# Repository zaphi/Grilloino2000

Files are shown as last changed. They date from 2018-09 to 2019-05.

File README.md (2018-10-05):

# Grilloino2000

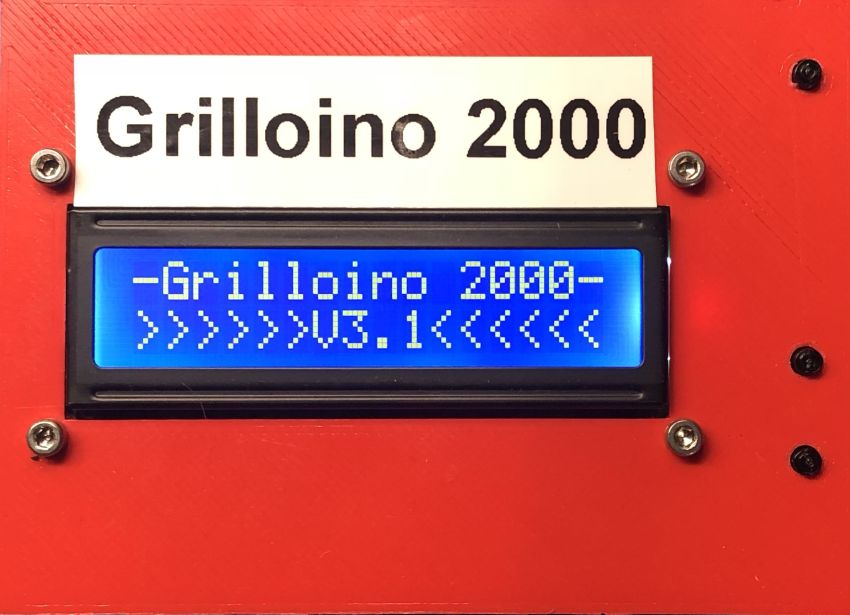
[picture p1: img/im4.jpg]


ESP8266 Grillthermometer

Als leidenschaftlicher Griller war es dies Jahr zeit für einen Smoker! Da kaufen nicht in frage kommt wurde der Bau eines UDS geplant. Und da ich in der Nacht gerne Schlafe und nicht alle halbe Stunde zum Smoker laufen möchte, musste man hier automatisieren.

Bauteile:
- ESP8266 NodeMCU
- 4051N Analogmultiplexer
- 16x2 LCD
- kleinkram... siehe BOM.txt

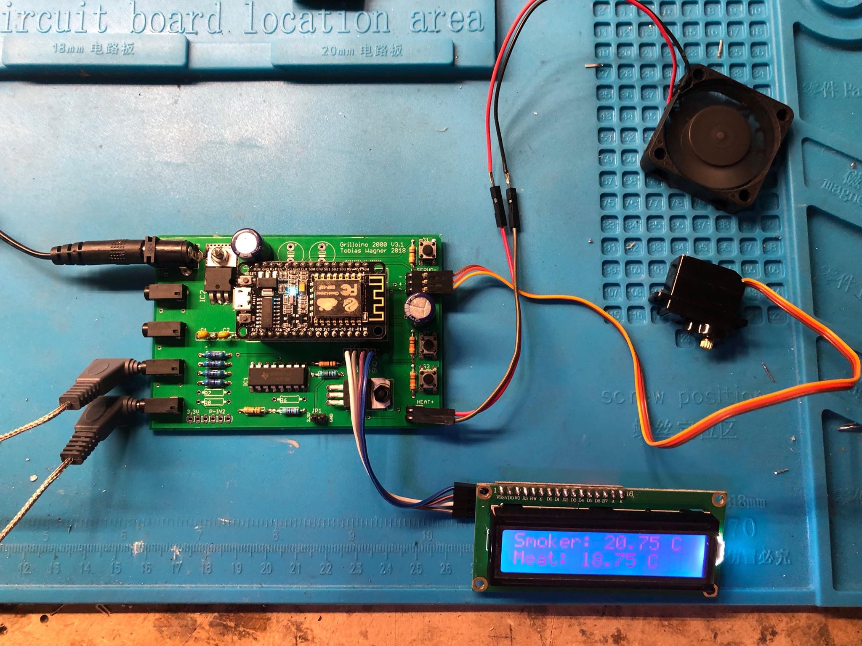
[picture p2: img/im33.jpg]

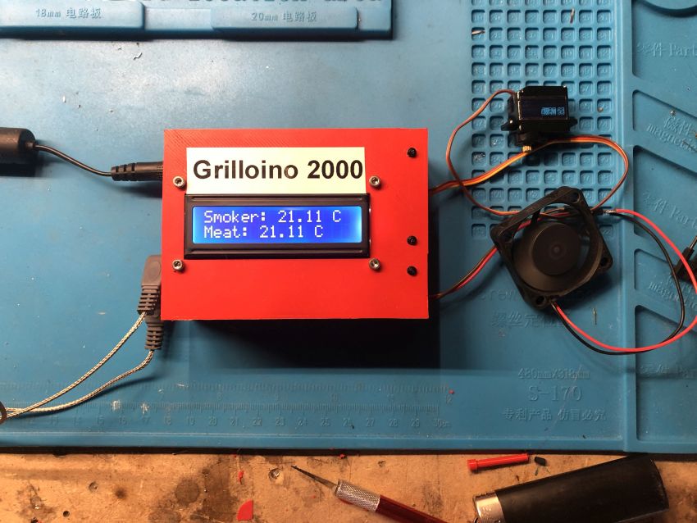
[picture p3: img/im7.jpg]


Funktionen:
- 1x Garraum
- 1-3x Kerntemperatur
- WIFI
- Handy App mittels Blynk
- Thingspeak Logging
- Pitmaster (Lüfter/Klappe)
- Push Nachrichten
- HTTP Server (wird vermutlich entfernt)

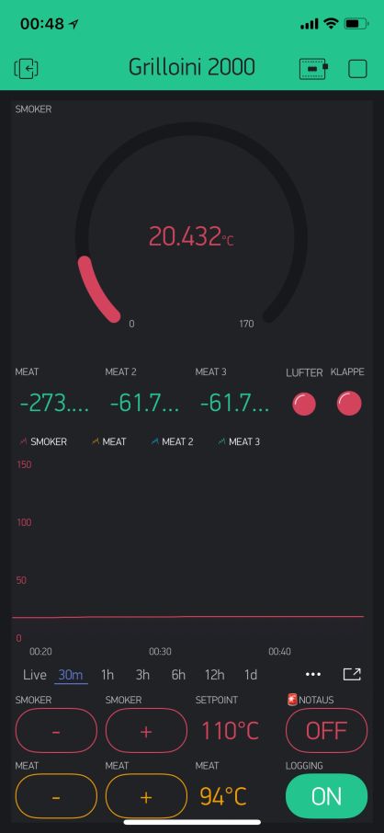
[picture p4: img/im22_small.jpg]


Aktueller Projektstand:
- PCB V3.1 incl. Buttons 
- 3D Druck Gehäuse

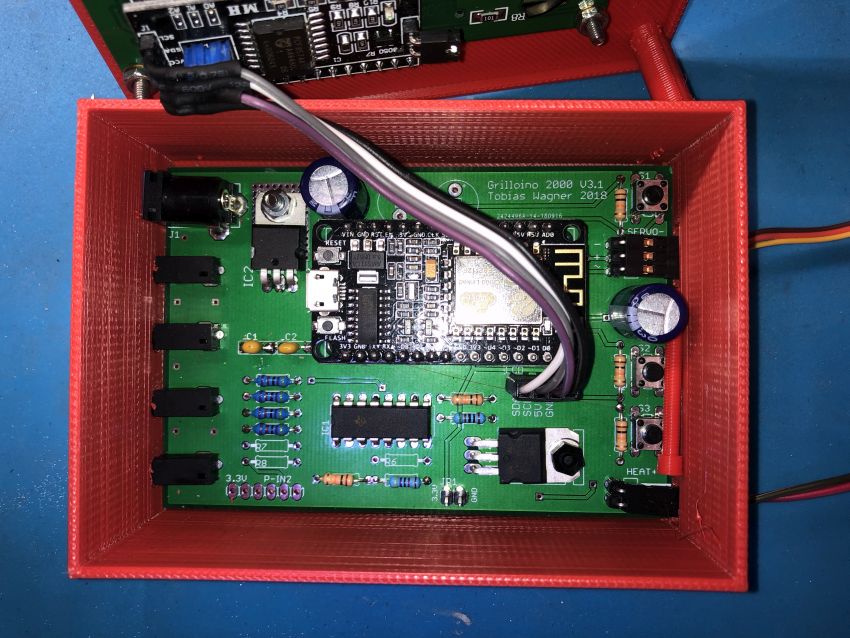
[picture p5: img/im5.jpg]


ToDo:
- korrektur Polung DC Stecker in PCB V3.2

HowTo:
- Es können theoretisch  alle Fühler verwendet werden die auch beim [WLANThermo V2](https://github.com/WLANThermo/WLANThermo_v2/tree/master/software/usr/share/doc/WLANThermo/probedata) funktionieren. Dort wird auch mittels der Steinhart-Hart-Gleichung gerechnet somit können die Parameter A,B,C und Rn übernommen werden. Danke für das vermessen der  Sensoren :-)

Aktuell eingepflegt:
- Maverick ET-7/71/72/73/77/901b
- Maverick ET-735
- Maverick ET-732/733
- Ikkea Fantast
- Ikkea Fantast Neu

Einstellungen für Blynk:
- char auth[] = "PUT YOUR CODE HEAR";

Einstellungen Thingspeak
- const int channelID = Your ID;
- String writeAPIKey = "Your Key";

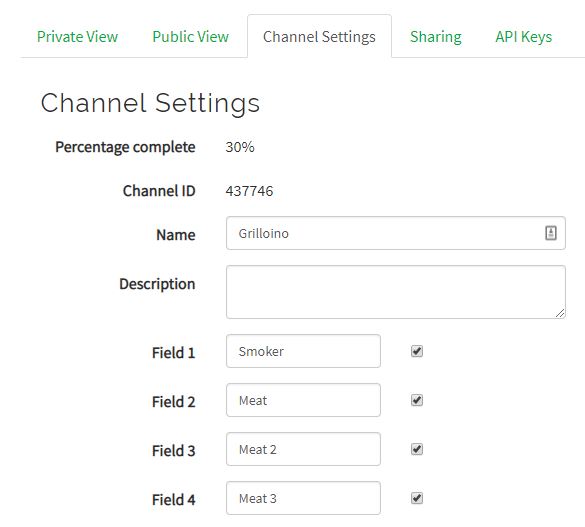
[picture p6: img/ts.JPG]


Messen und Korrektur V3.3:
- Spannung an JP1 messen und im Code eintragen z.B. 3.293V
- float vin = 3.293;  

Button S1:
- Startet WiFi Konfigurations Mode. Grilloino wird als AP im Handy sichtbar und kann mit jedem beliebigen
Hotspot verubnden werden.

Button S2:
- Doppelklick -> Menü Seite -
- Einfach Klick -> Wert +1
- Langer Klick -> Wert ++

Button S3:
- Doppelklick -> Menü Seite +
- Einfach Klick -> Wert -1
- Langer Klick -> Wert --
- Langer Klick nicht im Menü -> anzeige Spannung, IP und RSSI

Bauteile:
- R1-R4 47kOhm Messwiderstand
- R5 560 Ohm
- R9,R10,R11,R13,R14 10kOhm
- R12 47 kOhm

- C1 0,33uf
- C2 0,1uf
- C3,C4,C5,C6 1000 uf
- IC2 LM7805
- Q1 STP36NF06L
- IC1 4051N

Benötigte libraries:

- [Wifi Manager](https://github.com/tzapu/WiFiManager)
- [OneButton](https://github.com/mathertel/OneButton)
- [Timer](https://github.com/JChristensen/Timer)
- [LiquidCrystal-I2C-library](https://github.com/fdebrabander/Arduino-LiquidCrystal-I2C-library)
- [Blynk](https://github.com/blynkkk/blynk-library/releases/tag/v0.5.4)
- [PID-Library](https://github.com/br3ttb/Arduino-PID-Library)

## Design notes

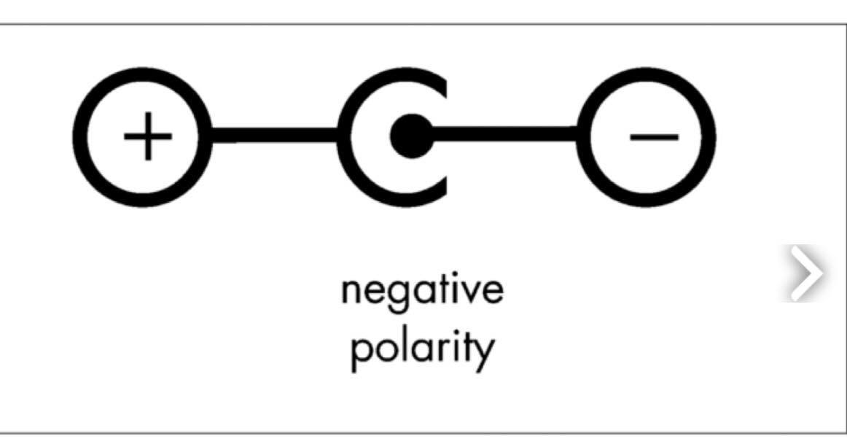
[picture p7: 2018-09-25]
img/pinoout.jpg

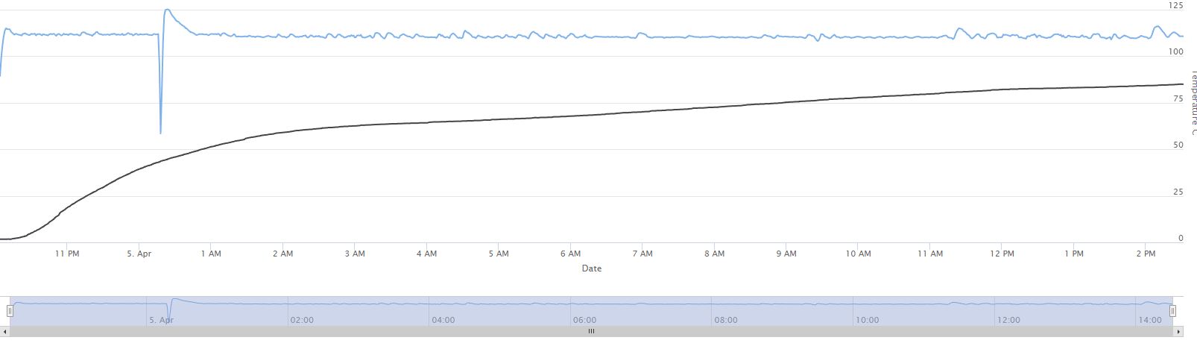
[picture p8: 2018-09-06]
img/te.JPG

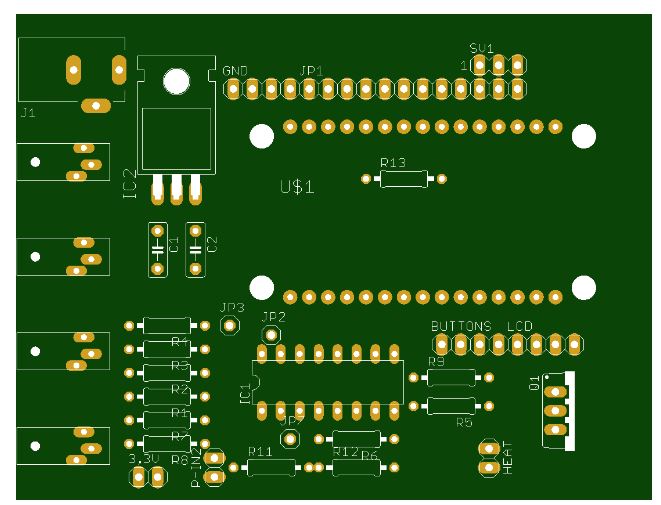
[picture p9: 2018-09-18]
img/pcb_v3.JPG

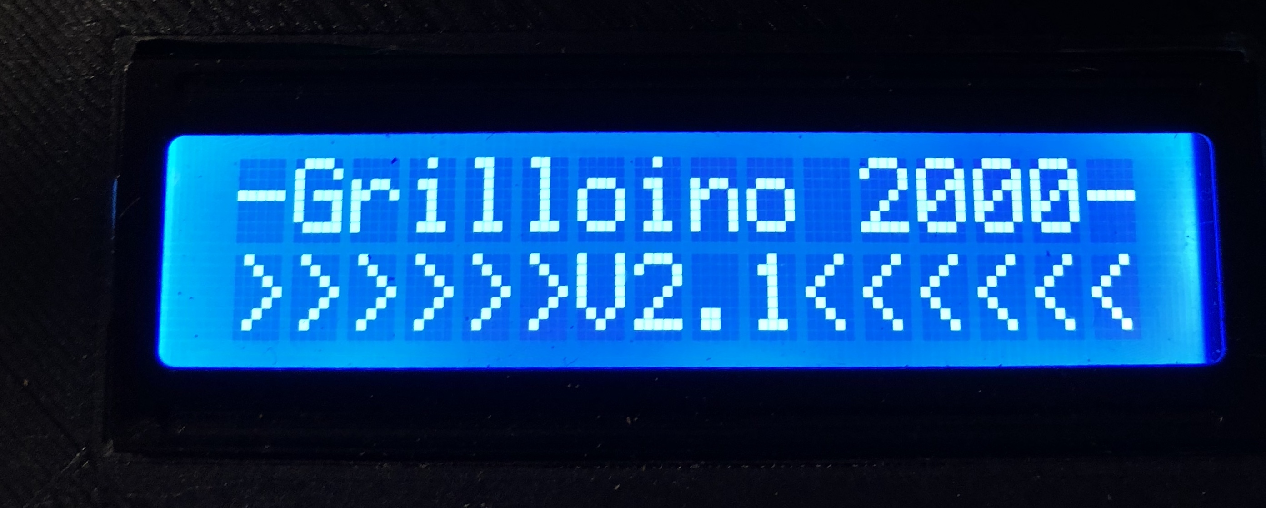
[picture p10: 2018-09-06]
img/im1.jpg

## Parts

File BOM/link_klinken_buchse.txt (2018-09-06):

https://www.digitalo.de/products/366744/Klinken-Steckverbinder-2.5mm-Buchse-Einbau-horizontal-Polzahl-2-Mono-Schwarz-1St..html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

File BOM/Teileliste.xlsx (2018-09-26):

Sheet: Teileliste
Bezeichnung | Wert | Stückzahl | Preis | Preis Gesamt | Link
Messwiderstand 0,1% | 47K | 4 | 0.35 € | 1.40 € | https://www.reichelt.de/widerstand-metallschicht-47-kohm-0207-0-6-w-0-1-mpr-47-0k-p12982.html?trstct=pol_6
Widerstand | 47k | 1 | 0.10 € | 0.10 € | https://www.reichelt.de/5-Kohleschichtwiderstaende/2/index.html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
Widerstand | 10k | 5 | 0.10 € | 0.52 € | https://www.reichelt.de/widerstand-kohleschicht-10-kohm-0207-250-mw-5-1-4w-10k-p1338.html?trstct=pos_2
Widerstand | 560 Ohm | 1 | 0.10 € | 0.10 € | https://www.reichelt.de/widerstand-kohleschicht-560-ohm-0207-250-mw-5-1-4w-560-p1446.html?trstct=pos_4
N-FET | STP36NF06L | 1 | 0.69 € | 0.69 € | https://www.reichelt.de/mosfet-n-ch-60v-30a-70w-to-220ab-stp-36nf06l-stm-p217327.html?&trstct=pos_0
ESP8266 NodeMCU | ESP8266 | 1 | 7.55 € | 7.55 € | https://www.amazon.de/gp/product/B018E741G4/ref=oh_aui_search_detailpage?ie=UTF8&psc=1
Kondensator | 0,33uF | 1 | 0.22 € | 0.22 € | https://www.reichelt.de/folienkondensator-330nf-50v-rm5-mks2-50-330n-p172678.html?&trstct=pos_1
Kondensator | 0,1uF | 1 | 0.20 € | 0.20 € | https://www.reichelt.de/folienkondensator-100nf-63v-rm5-mks2-63-100n-p12349.html?&trstct=pol_2
Kondensator | 1000uf | 4 | 0.25 € | 1.00 € | https://www.reichelt.de/elko-radial-1-0-mf-6-3-v-rm-3-5-1000h-105-c-20-nhg-a-1-0m-6-3-p200391.html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
Multiplexer | 4051N | 1 | 0.40 € | 0.40 € | https://www.reichelt.de/ic-schaltung-74hct-4051-p3393.html?&trstct=pos_0
Spannungsregler | 7805T | 1 | 0.52 € | 0.52 € | https://www.reichelt.de/spannungsregler-5-v-to-220fp-l7805cp-stm-p216931.html?&trstct=pos_1
Stiftleisten | 2,54 mm Raster | 2 | 0.17 € | 0.34 € | https://www.reichelt.de/36pol-stiftleiste-gerade-rm-2-54-sl-1x36g-2-54-p19504.html?&trstct=pol_0
DC Buchse | DCJ0303 | 1 | 0.99 € | 0.99 € | https://www.reichelt.de/einbaubuchse-aussen-6-3-mm-innen-2-1-mm-dc-bu-072759-p208065.html?trstct=pos_7
Klinkenbuchse | 2,5mm Mono | 4 | 1.13 € | 4.52 € | https://www.conrad.de/de/klinken-steckverbinder-25-mm-buchse-einbau-horizontal-polzahl-2-mono-schwarz-conrad-components-1-st-718780.html
LCD | 16x2 | 1 | 9.80 € | 9.80 € | https://www.reichelt.de/entwicklerboards-display-16-x-2-zeichen-blau-debo-lcd-16x2-bl-p192143.html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
Button | Printtaster | 3 | 0.25 € | 0.75 € | https://www.reichelt.de/printtaster-tht-2-45-n-6-x-6-x-9-5-mm-rnd-210-00196-p226417.html?trstct=pos_3
Verpolungsschutz | Diode 1N4001 | 2 | 0.02 € | 0.04 € | https://www.reichelt.de/gleichrichterdiode-50-v-1-a-do-41-1n-4001-p1723.html?&trstct=pos_0
 |  |  | Gesamt | 29.14 €
Lüfter
Radial Lüfter AVC BA10033B12HP077-F22 95x97x33mm |  | 1 | 4.85 | 4.85 | https://www.ebay.de/itm/Radial-Lufter-AVC-BA10033B12HP077-F22-95x97x33mm-Lufter-Fan-12-V-3600-U-min/183452984131
Mini Servo |  | 1 | 3.99 | 3.99 | https://www.ebay.de/itm/1-2-4-10pcs-9G-SG90-Mini-Gear-Micro-Servo-Motor-Robot-Helicopter-Fernbedienung/123106210417

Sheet: Tabelle1
Part | Value | Device | Package | Library | Sheet
3,3V |  | PINHD-1X2 | 1X02 | pinhead | 1
BUTTONS |  | PINHD-1X4 | 1X04 | pinhead | 1
C1 | 0,33uF | C5/2.5 | C5B2.5 | capacitor-wima | 1
C2 | 0,1uF | C5/2.5 | C5B2.5 | capacitor-wima | 1
GND |  | PINHD-1X4 | 1X04 | pinhead | 1
HEAT |  | PINHD-1X2 | 1X02 | pinhead | 1
IC1 | 4051N | 4051N | DIL16 | 40xx | 1
IC2 | 7805T | 7805T | TO220H | linear | 1
J1 |  | DCJ0303 | DCJ0303 | con-jack | 1
JP1 |  | PINHD-1X12 | 1X12 | pinhead | 1
JP2 |  | PINHD-1X1 | 1X01 | pinhead | 1
JP3 |  | PINHD-1X1 | 1X01 | pinhead | 1
JP7 |  | PINHD-1X1 | 1X01 | pinhead | 1
LCD |  | PINHD-1X4 | 1X04 | pinhead | 1
P-IN2 |  | PINHD-1X2 | 1X02 | pinhead | 1
Q1 | STP36NF06L | IRF540 | TO220BV | transistor-power | 1
R1 | 47k | R-EU_0207/10 | 0207/10 | rcl | 1
R2 | 47k | R-EU_0207/10 | 0207/10 | rcl | 1
R3 | 47k | R-EU_0207/10 | 0207/10 | rcl | 1
R4 | 47k | R-EU_0207/10 | 0207/10 | rcl | 1
R5 | 560 | R-EU_0207/10 | 0207/10 | rcl | 1
R6 | 47k | R-EU_0207/10 | 0207/10 | rcl | 1
R7 | 47k | R-EU_0207/10 | 0207/10 | rcl | 1
R8 | 47k | R-EU_0207/10 | 0207/10 | rcl | 1
R9 | 10k | R-EU_0207/10 | 0207/10 | rcl | 1
R11 | 1k | R-EU_0207/10 | 0207/10 | rcl | 1
R12 | 4k7 | R-EU_0207/10 | 0207/10 | rcl | 1
R13 | 4700 | R-EU_0207/10 | 0207/10 | rcl | 1
SV1 |  | MA03-1 | MA03-1 | con-lstb | 1
U$1 | ESP12E_DEVKIT | ESP12E_DEVKIT | ESP12E_DEVKIT | ESP12E_DEVKIT | 1
U$3 | JACK_2_5 | JACK_2_5 | JACK_2_5 | 2_5mm_jack | 1
U$4 | JACK_2_5 | JACK_2_5 | JACK_2_5 | 2_5mm_jack | 1
U$5 | JACK_2_5 | JACK_2_5 | JACK_2_5 | 2_5mm_jack | 1
U$6 | JACK_2_5 | JACK_2_5 | JACK_2_5 | 2_5mm_jack | 1

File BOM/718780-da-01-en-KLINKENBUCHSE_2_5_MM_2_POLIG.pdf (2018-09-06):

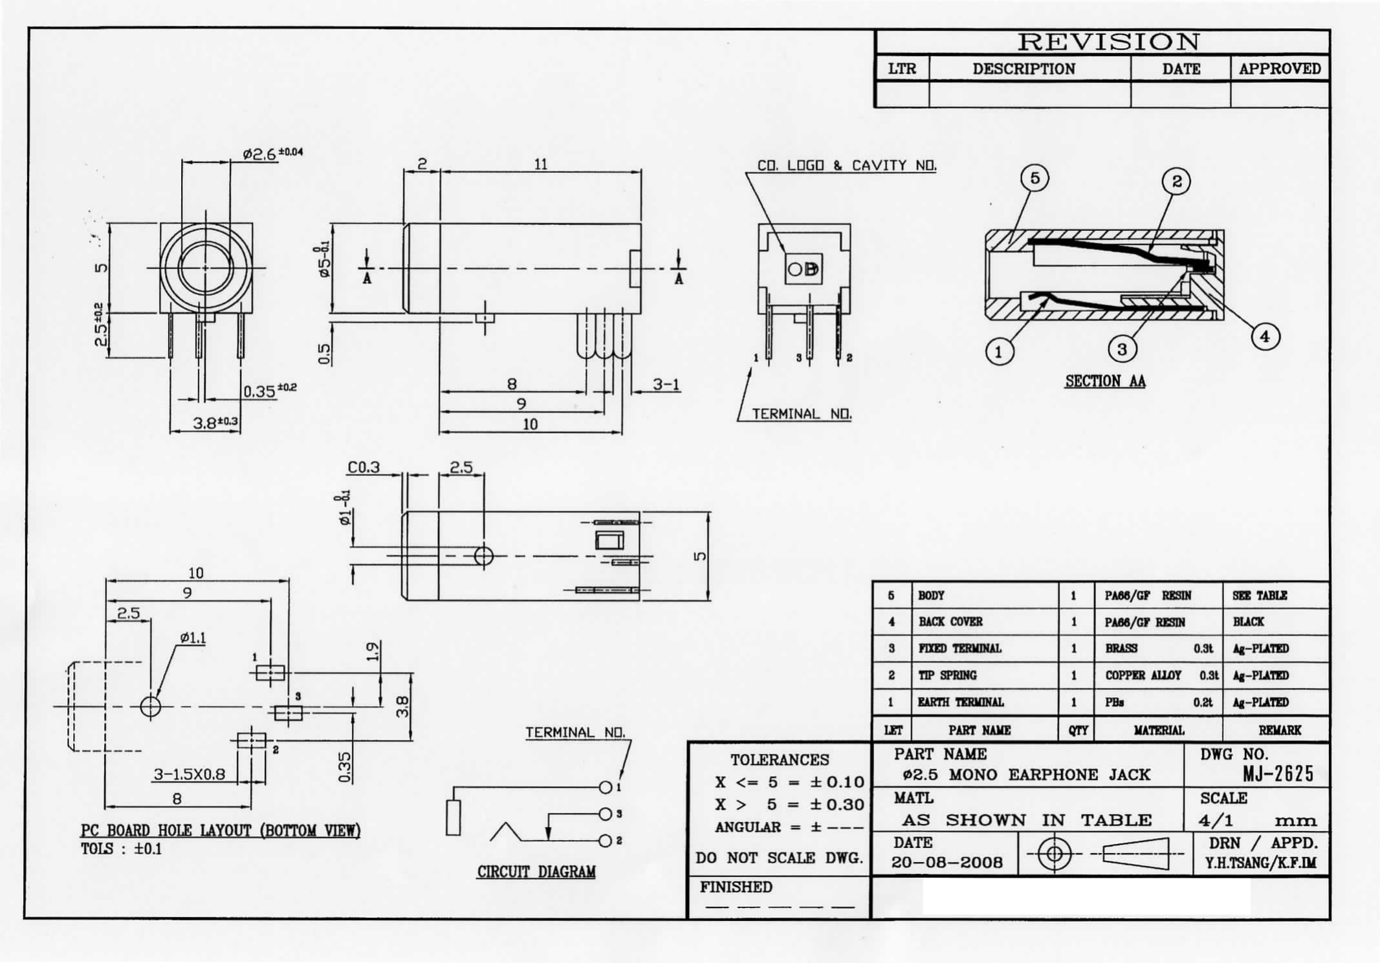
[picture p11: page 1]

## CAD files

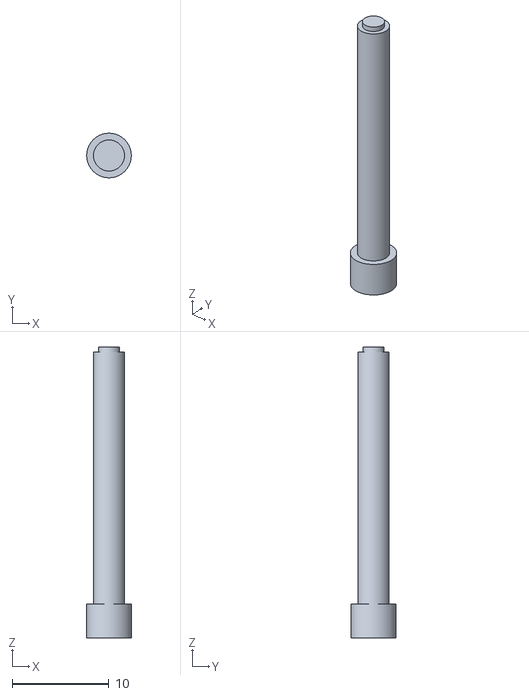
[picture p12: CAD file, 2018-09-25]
3D-Print/Case/button.stl
4.60 x 4.60 x 30.0

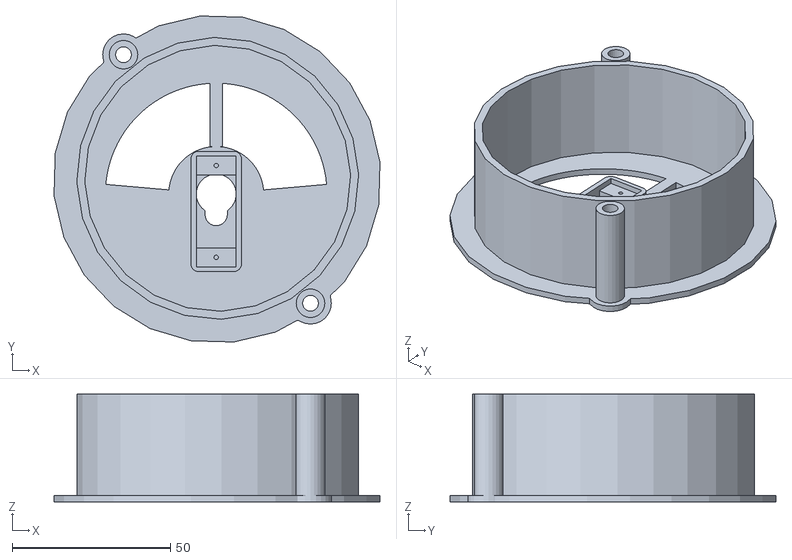
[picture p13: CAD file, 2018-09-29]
3D-Print/Fan/box.stl
103.0 x 103.0 x 34.0

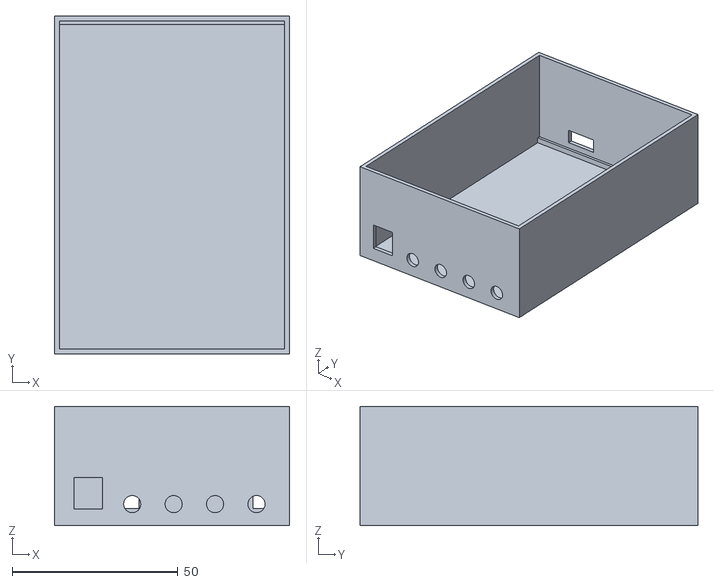
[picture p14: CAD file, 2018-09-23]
3D-Print/Case/unten.stl
71.0 x 102.0 x 36.0

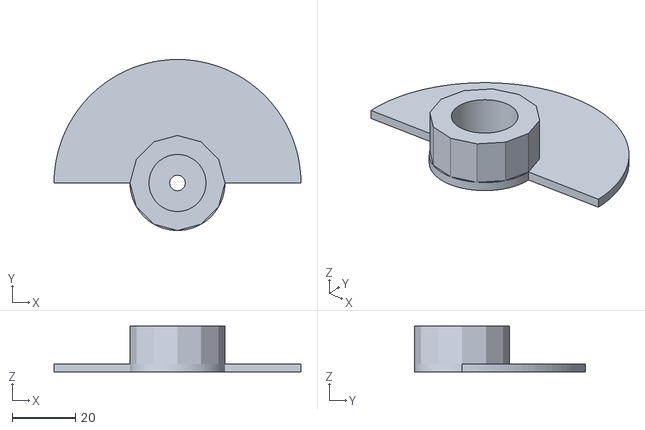
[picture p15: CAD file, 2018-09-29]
3D-Print/Fan/servodamper-rotor.stl
78.0 x 54.0 x 14.5

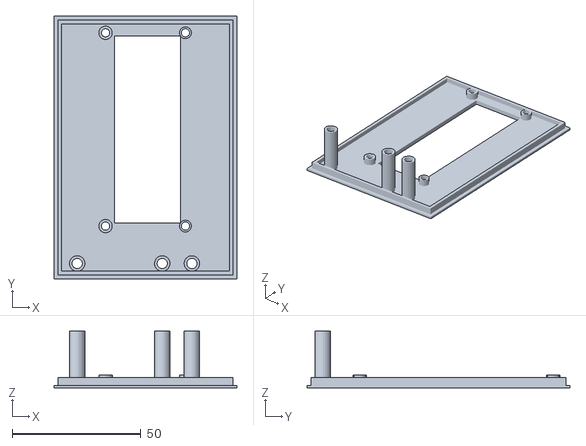
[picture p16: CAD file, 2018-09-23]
3D-Print/Case/oben.stl
71.0 x 102.0 x 22.0

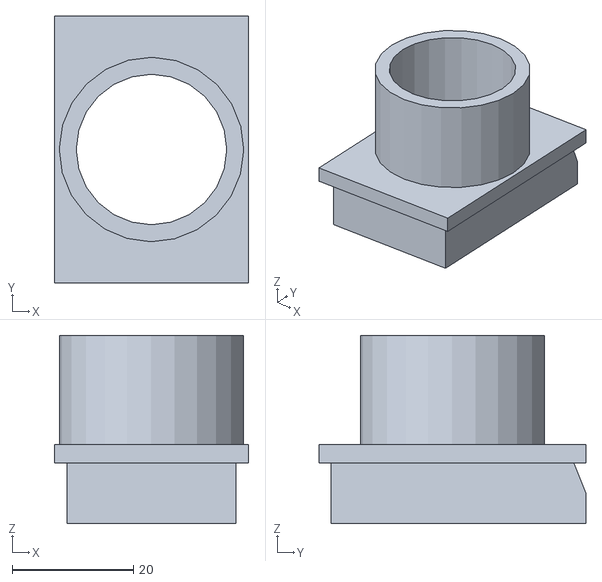
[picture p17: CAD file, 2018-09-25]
3D-Print/Fan/lüfter_1zoll.stl
32.0 x 44.0 x 31.0

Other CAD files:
3D-Print/Case/button.skp
3D-Print/Case/oben.skp
3D-Print/Case/unten.skp
3D-Print/Fan/lüfter_1zoll.skp

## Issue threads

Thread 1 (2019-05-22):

Maverick Fühler anschließen

rgruebel, 2019-05-22:
Hallo,
ich will auch einen WLAN-Thermometer bauen und schaue mir bei deinem Projekt einiges ab. In einem simplen Aufbau versuche ich im Moment sinnvolle Werte von meinen Fühlern auszulesen aber komme leider auf keinen grünen Zweig. Kannst du vlt einen Blick auf meine Verkabelung werfen und hast eine Idee was da nicht passt?
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

zaphi, 2019-09-03:
Hi, den Maverick Fühler gibt es auch mit einem widerstand von 1000Ohm das musst du in der probe.h dementsprechend anpassen. sonst zeigt er immer 0 Grad an.

Closed 2019-10-22.

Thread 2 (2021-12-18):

Nachbau des Grilloino

trench29, 2021-12-18:
Hi, auf der Suche nach einem WLAN-fähigen Grillthermometer, bin ich auf dein ESP8266 Projekt gestoßen. Tolles Projekt und sehr nett, dass du es öffentlich geteilt hast!

Würdest du vielleicht den aktuellen bzw. letzten Schaltplan von der v.3.2 veröffentlichen?
So wie ich das sehe, ist im Projekt noch eine ältere Version vorhanden.

Ich würde dein Projekt gerne nachbauen und etwas anpassen, da ich die PID Temperatursteuerung über den Servo und dem Lüfter nicht benötige. Mir reicht nur die Temperaturüberwachung des Grillraums und des Fleisches, da ich einen Gasgrill habe.

Meinst du, ich könnte die Platine nachbauen und deine Programmierung verwenden, ohne dass ich einen Servo und Lüfter anschließe? Oder würde das im laufenden Betrieb zu Problemen mit dem ESP8266 führen? Leider habe ich noch nicht so viel Erfahrung mit der ESP bzw. Arduino Programmierung, weshalb ich den Programmiercode nicht ohne weiteres anpassen kann.

Freue mich über eine Rückmeldung von dir!

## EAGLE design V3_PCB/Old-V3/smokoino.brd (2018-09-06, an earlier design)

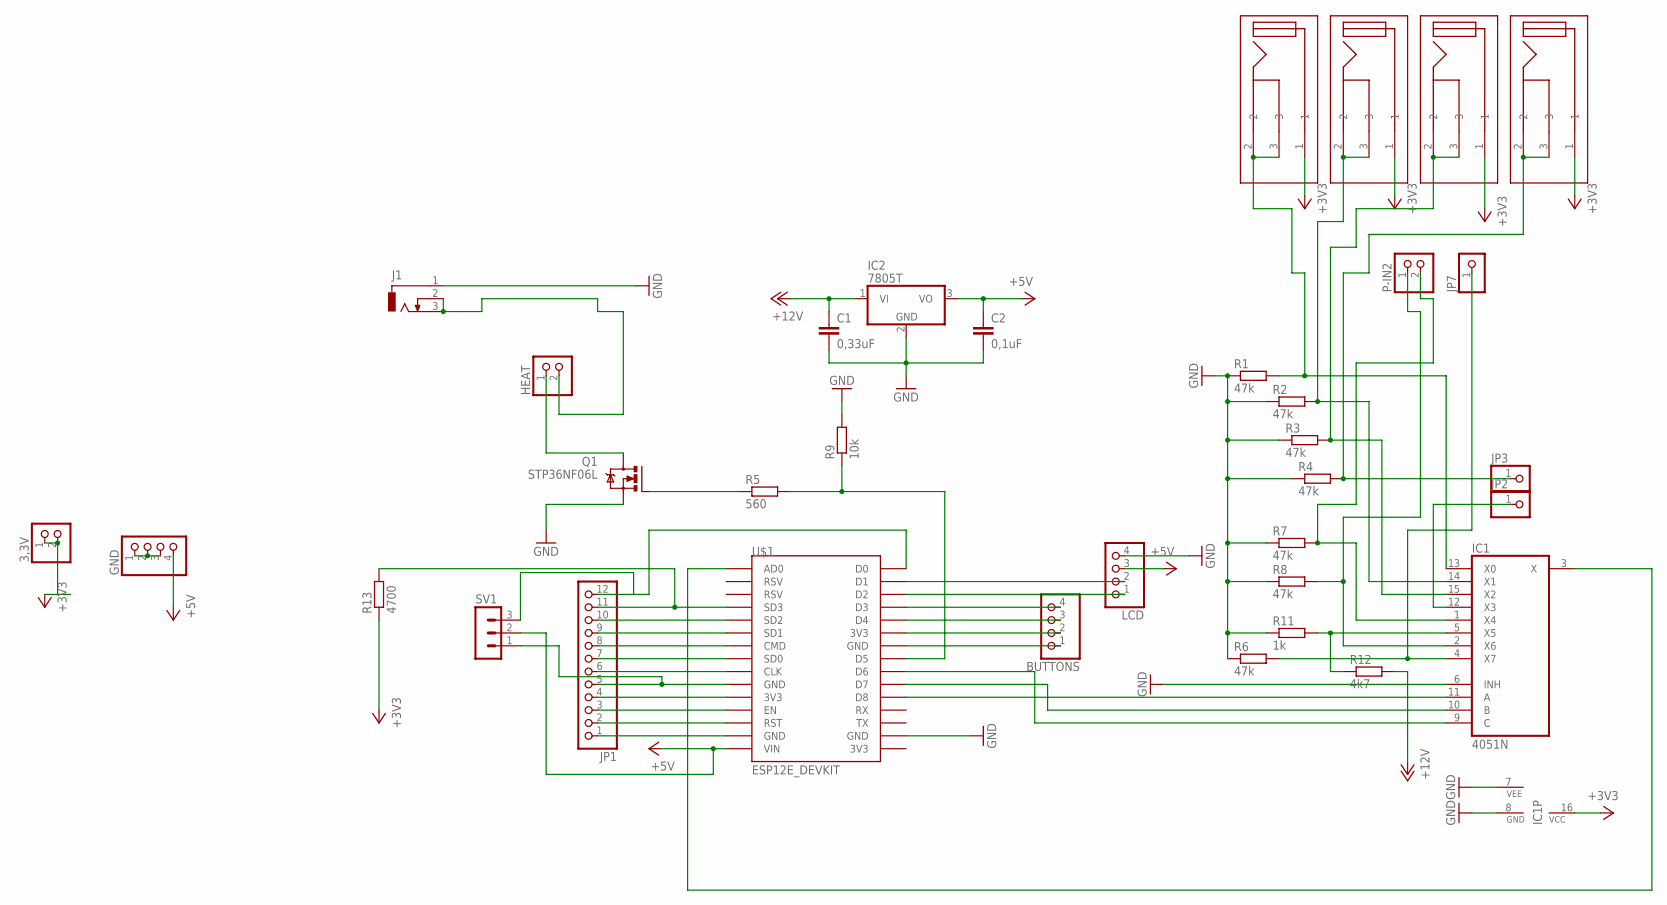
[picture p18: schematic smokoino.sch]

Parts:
3,3V: PINHD-1X2; 1X02
BUTTONS: PINHD-1X4; 1X04
C1: 0,33uF; C5B2.5
C2: 0,1uF; C5B2.5
GND: PINHD-1X4; 1X04
HEAT: PINHD-1X2; 1X02
IC1: 4051N; DIL16
IC2: 7805T; TO220H
J1: DCJ0303
JP1: PINHD-1X12; 1X12
JP2, JP3, JP7: PINHD-1X1; 1X01
LCD: PINHD-1X4; 1X04
P-IN2: PINHD-1X2; 1X02
Q1: STP36NF06L; TO220BV
R1, R2, R3, R4, R6, R7, R8: 47k; 0207/10
R5: 560; 0207/10
R9: 10k; 0207/10
R11: 1k; 0207/10
R12: 4k7; 0207/10
R13: 4700; 0207/10
SV1: MA03-1
U$1: ESP12E_DEVKIT
U$3, U$4, U$5, U$6: JACK_2_5

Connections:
4051: IC1.4 (X7), JP7.1, R6.2
+3V3: 3,3V.1, 3,3V.2, IC1.16 (VCC), JP1.4, R13.1, U$1.3V3@0 (3V3), U$3.1, U$4.1, U$5.1, U$6.1
+5V: C2.1, GND.4, IC2.3 (VO), LCD.3, SV1.2, U$1.VIN
+12V: C1.1, HEAT.2, IC2.1 (VI), J1.2, J1.3, R12.2
GND: BUTTONS.1, C1.2, C2.2, GND.1, GND.2, GND.3, IC1.6 (INH), IC1.7 (VEE), IC1.8 (GND), IC2.2 (GND), J1.1, JP1.1, JP1.5, LCD.4, Q1.S, R1.1, R2.1, R3.1, R4.1, R6.1, R7.1, R8.1, R9.2, R11.1, SV1.1, U$1.GND@0 (GND), U$1.GND@1 (GND), U$1.GND@2 (GND), U$1.GND@3 (GND)
unnamed: IC1.9 (C), U$1.D6
unnamed: IC1.10 (B), U$1.D7
unnamed: IC1.11 (A), U$1.D8
unnamed: IC1.3 (X), U$1.AD0
unnamed: IC1.13 (X0), R1.2, U$3.2, U$3.3
unnamed: IC1.14 (X1), R2.2, U$4.2, U$4.3
unnamed: BUTTONS.4, U$1.D3
unnamed: BUTTONS.3, U$1.D4
unnamed: LCD.1, U$1.D2
unnamed: LCD.2, U$1.D1
unnamed: IC1.15 (X2), R3.2, U$5.2, U$5.3
unnamed: IC1.5 (X5), R11.2, R12.1
unnamed: JP1.10, U$1.SD2
unnamed: IC1.12 (X3), JP2.1
unnamed: IC1.2 (X6), P-IN2.1, R8.2
unnamed: R5.2, R9.1, U$1.D5
unnamed: JP1.2, U$1.RST
unnamed: JP1.3, U$1.EN
unnamed: BUTTONS.2, U$1.3V3@1 (3V3)
unnamed: JP1.6, U$1.CLK
unnamed: JP1.7, U$1.SD0
unnamed: JP1.8, U$1.CMD
unnamed: JP1.9, U$1.SD1
unnamed: Q1.G, R5.1
unnamed: JP1.11, R13.2, U$1.SD3
unnamed: JP1.12, SV1.3, U$1.D0
unnamed: IC1.1 (X4), P-IN2.2, R7.2
unnamed: JP3.1, R4.2, U$6.2, U$6.3
STP36NF06L: HEAT.1, Q1.D

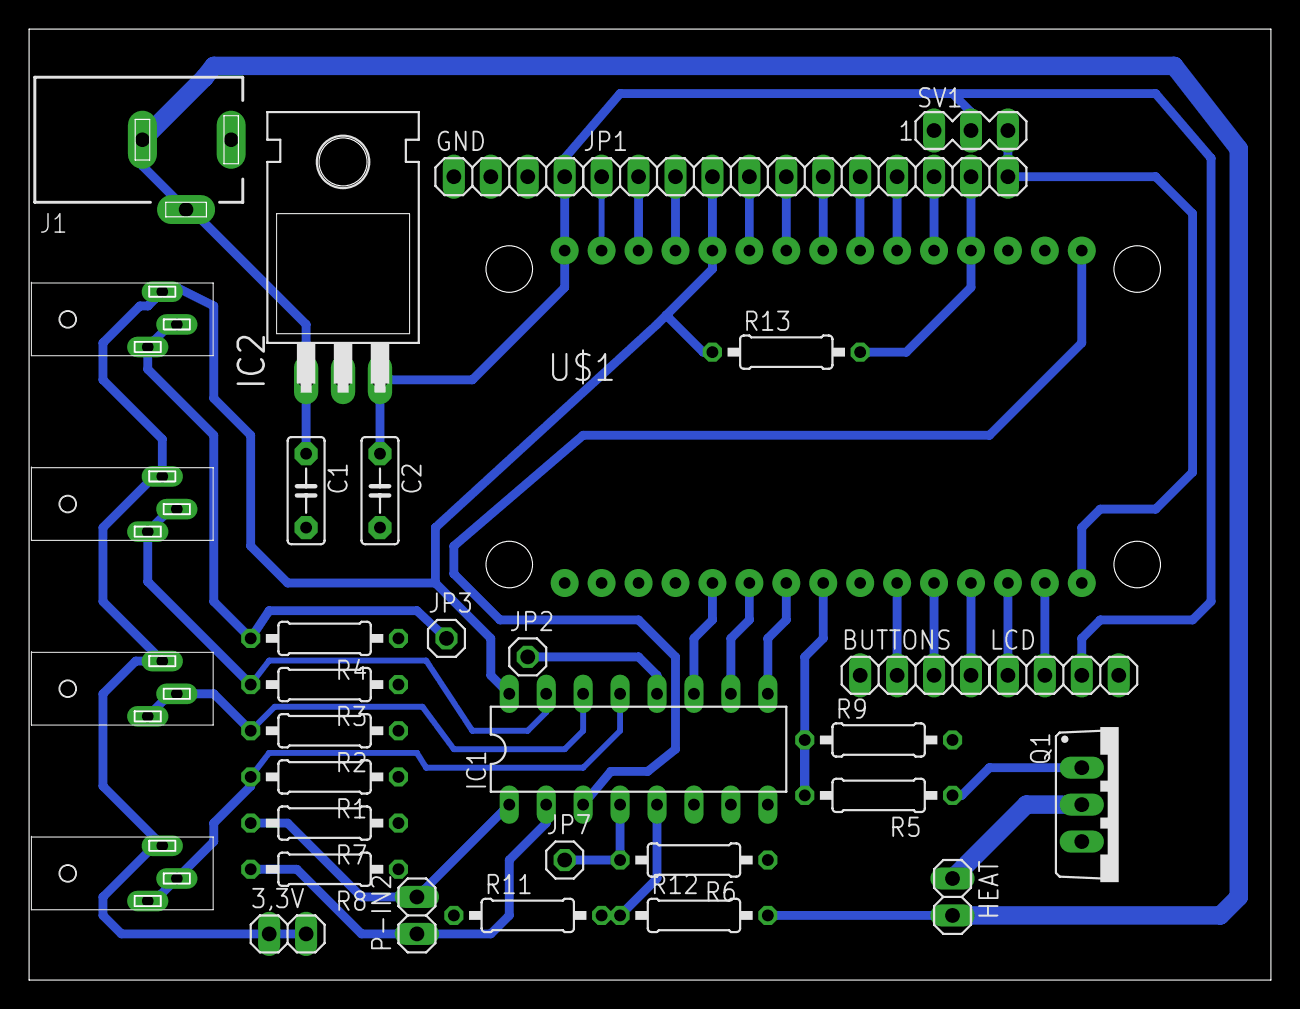
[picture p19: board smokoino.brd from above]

Board: 2 copper layers, 85.4 x 65.4 mm, 34 parts (0 on the bottom side), 34 nets.

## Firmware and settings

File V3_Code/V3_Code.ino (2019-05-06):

#include <FS.h> //this needs to be first, or it all crashes and burns...
#include <ESP8266WiFi.h>          //https://github.com/esp8266/Arduino
#include <DNSServer.h>
#include <ESP8266WebServer.h>
#include <WiFiManager.h>          //https://github.com/tzapu/WiFiManager
#include "OneButton.h"
#include <SPI.h>
#include <Timer.h>
#include <Wire.h>
#include <LiquidCrystal_I2C.h>
#include <BlynkSimpleEsp8266.h>
#include <math.h>
#include <OneWire.h>
#include <PID_v1.h>
#include <Servo.h>
#include "probe.h"
/********************************************************************/
//debug
/********************************************************************/
#define DEBUG
/********************************************************************/
//probe´s in probe.h 
/********************************************************************/
// see probe.h Ikkea Fantast = A_FANT, B_FANT, C_FANT and rn_FANT set it for smoker, meat, meat 2 and meat 3 acording your porbe
// smoker probe 
float A = A_ET73;      // "A" Coeffecient in Steinhart-Hart Equation
float B = B_ET73;      // "B"
float C = C_ET73;      // "C"
int rn1 = rn_ET73;
//meat probe
float A2 = A_ET73;      // "A" Coeffecient in Steinhart-Hart Equation
float B2 = B_ET73;      // "B"
float C2 = C_ET73;      // "C"
int rn2 = rn_ET73;
//meat2 probe
float A3 = A_ET73;      // "A" Coeffecient in Steinhart-Hart Equation
float B3 = B_ET73;      // "B"
float C3 = C_ET73;      // "C"
int rn3 = rn_ET73;
//meat3 probe
float A4 = A_ET73;      // "A" Coeffecient in Steinhart-Hart Equation
float B4 = B_ET73;      // "B"
float C4 = C_ET73;      // "C"
int rn4 = rn_ET73;
/********************************************************************/
/********************************************************************/
/********************************************************************/
float vin = 3.293;              //  DC Voltage as measured with DMM between +3.3 and GND
float r2 = 47000;                // Resistance in ohms of your fixed resistor
float r22 = 47000;                // Resistance in ohms of your fixed resistor
float r23 = 47000;                // Resistance in ohms of your fixed resistor
float r24 = 47000;                // Resistance in ohms of your fixed resistor
float r25 = 47000;                // Resistance in ohms of your fixed resistor bestÃ¼ckt aber nicht verwendet Multiplexer kanal 4(5)
float r27 = 47000;                // Resistance in ohms of your fixed resistor bestÃ¼ckt aber nicht verwendet Multiplexer kanal 6(7)
/********************************************************************/
/********************************************************************/
/**************************************
******************************/
// ThingSpeak und Blynk Settings Grilloino
//blynk
char auth[] = "";
//thingspeak
const char* host = "api.thingspeak.com";
const int channelID = 5;
String writeAPIKey = "d"; // write API key for your ThingSpeak Channel
/********************************************************************/
/********************************************************************/
/********************************************************************/
/********************************************************************/
String vers = "V3.2.1";
/********************************************************************/
/********************************************************************/
int lowTemp;              //  Low limit warning for smoker temp
int highTemp;            // High limit warning for smoker temp
int setPoint = 110;
int meatDone = 94;            // Temperature at which your meat is done
int meatDone2 = 94;            // Temperature at which your meat is done
int meatDone3 = 94;            // Temperature at which your meat is done
/********************************************************************/
/********************************************************************/
/********************************************************************/
/********************************************************************/
/********************************************************************/
/********************************************************************/
/********************************************************************/
/********************************************************************/
//Pins zuweisen Layout v3
#define pushPin 14              //D3 connect Fet or Transistor for fan
#define pA 15                   //D8 Multiplexer A
#define pB 13                   //D7 Multiplexer B
#define pC 12                    //D6 Multiplexer C
// WIFI manager Triger Pin
#define TRIGGER_PIN 10
int servoPin = 16;
//Buttons
OneButton mbutton(2, true);    //D6 Menue Button
OneButton sbutton(0, true);    //D4 select button
/********************************************************************/
/********************************************************************/
/********************************************************************/
/********************************************************************/
////Pins zuweisen Layout v2
//#define pushPin 0               //D3 connect Fet or Transistor for fan
//#define pA 15                   //D8 Multiplexer A
//#define pB 13                   //D7 Multiplexer B
//#define pC 12                    //D6 Multiplexer C
// WIFI manager Triger Pin
//#define TRIGGER_PIN 10
//int servoPin = 16;
////Buttons
//OneButton mbutton(14, true);    //D6 Menue Button
//OneButton sbutton(2, true);    //D4 select button

LiquidCrystal_I2C lcd(0x3F, 16, 2); //D2 & D1
Servo myservo;  // create servo object to control a servo
WiFiClient client;
WiFiServer server(80);
WidgetLED FAN(V9);
WidgetLED KLAPPE(V20);
double highTempd;
double setPointd;
int pushMode = 0;               // Pushingbox 1 = on 0= off
int logMode = 1;                // Thingspeak Loggin 1 = on 0= off
int httpMode = 1;               // Http Server 1 = on 0= off
int menue = 0;                  // Menue off
int displaymode = 1;           // Menue pages
int logstate;
int pushstate;
int httpstate;
int idleMode = 0;
int idlestate;
int val;
int val2;
int valservo = 0;
int lowlim = 0;               // Values below this will considered erroneous
float air;                      //  Smoker temperature
float meat;                     //   Meat temperature
float meat2;                     //   Meat temperature
float meat3;                     //   Meat temperature
int probecount = 2;
int sensorValue = 0;
float volt;
float volt2;
float offset = 0;
float Acalc;
float Bcalc;
float Ccalc;
int rn;
float a0;
float v0;
float r0;
float rref;
float logr0;
float k0;
float f0;
int tempDown;
int tempUp;
double setPointd2;
int meatUp;
int meatDown;
int meatUp2;
int meatDown2;
int meatUp3;
int meatDown3;

Timer t;
double Output, Input;
double Output2, Input2;
double Kp = 30, Kp2 = 180, Ki = 0.005, Kd = 0.5;
PID myPID(&Input, &Output, &setPointd, Kp, Ki, Kd, DIRECT);
PID myPID2(&Input2, &Output2, &setPointd2, Kp2, Ki, Kd, DIRECT);
//*******************************************************************
//SETUP
//*******************************************************************
void setup() {
  myPID.SetMode(AUTOMATIC);
  myPID2.SetMode(AUTOMATIC);
  pinMode(pA, OUTPUT);
  pinMode(pB, OUTPUT);
  pinMode(pC, OUTPUT);
  // pusher init
  pinMode(pushPin, OUTPUT);
  pinMode(TRIGGER_PIN, INPUT_PULLUP);
  digitalWrite(pushPin, LOW);
  lcd.begin();
  lcd.setBacklight(HIGH);
  lcd.clear();
  lcd.home();
  lcd.print("-Grilloino 2000-");
  lcd.setCursor(0, 1);
  lcd.print(">>>>>>");
  lcd.print(vers);
  lcd.print("<<<<<<");

  
  Serial.begin(115200);
  Serial.println("-Grilloino 2000-");
  delay(3000);
  Serial.println();
  WiFi.begin();
  delay(5000);
  if (WiFi.status() == WL_CONNECTED) {

    Serial.println("connected...yeey :)");
    Serial.println("local ip");
    Serial.println(WiFi.localIP());
    lcd.clear();
    lcd.home();
    lcd.print("Connected!");
    lcd.setCursor(0, 1);
    lcd.print(WiFi.localIP());
    delay(1000);
    Blynk.config(auth);  // in place of Blynk.begin(auth, ssid, pass);
    Blynk.connect(3333);  // timeout set to 10 seconds and then continue without Blynk
    while (Blynk.connect() == false) {
      // Wait until connected
      Serial.println("Try to connect to Blynk ");
      lcd.clear();
      lcd.home();
      lcd.print("Try to connect");
      lcd.setCursor(0, 1);
      lcd.print("to Blynk");
    }
    Serial.println("Connected to Blynk server");
    lcd.clear();
    lcd.home();
    lcd.print("Connected");
    lcd.setCursor(0, 1);
    lcd.print("to Blynk");
    delay(500);
  }
  else {
    lcd.clear();
    lcd.home();
    lcd.print("No WiFi");
    lcd.setCursor(0, 1);
    lcd.print("No Blynk");
    delay(1000);
  }
  server.begin();
  t.every(2000, readSensors);
  t.every(3000, updateDisplay);
  t.every(60000, sendPush);
  t.every(10000, sendData);
  t.every(3500, pushHeat);
  t.every(3500, checkVolt);
  // link the button 1 functions.
  mbutton.attachClick(click1); // --
  mbutton.attachDoubleClick(doubleclick1); // menue
  mbutton.attachDuringLongPress(longPress1); // --
  // link the button 2 functions.
  sbutton.attachClick(click2); // ++
  sbutton.attachDuringLongPress(longPress2); //++
  sbutton.attachDoubleClick(doubleclick2); // menue
  myservo.attach(servoPin);  // attaches the servo on GIO2 to the servo object
  for (int i = 0; i < 180; i++) {
    myservo.write(i);
    delay(10);
  }
  for (int i = 180; i > 0; i--) {
    myservo.write(i);
    delay(10);
  }


  myservo.write(0);
}
void loop() {
  // is configuration portal requested?#
  wifiConfig();

  //Main Loop
  lowTemp = setPoint - 8;
  highTemp = setPoint + 8;
  highTempd = highTemp;
  setPointd = setPoint;
  setPointd2 = setPointd + 2;
  mbutton.tick();
  sbutton.tick();
  if (WiFi.status() == WL_CONNECTED) {
    Blynk.run();
  }
  if (0 == menue)
  {
    t.update();
    updatehttp();
  }
}

BLYNK_WRITE(V4)  // target temp down
{
  tempDown = param.asInt();
  if (tempDown == 1) {
    tempDownFunc();
  }
}
BLYNK_WRITE(V5) // target temp up
{
  tempUp = param.asInt();
  if (tempUp == 1) {
    tempUpFunc();
  }
}
BLYNK_WRITE(V7) // Logging on/off
{
  logstate = param.asInt();
  if (logstate == 1) {
    logMode = 1;
  }
  else {
    logMode = 0;
  }
}
BLYNK_WRITE(V8) // push on/off
{
  pushstate = param.asInt();
  if (pushstate == 1) {
    pushMode = 1;
  }
  else {
    pushMode = 0;
  }
}
BLYNK_WRITE(V19) // http on/off
{
  httpstate = param.asInt();
  if (httpstate == 1) {
    httpMode = 1;
  }
  else {
    httpMode = 0;
  }
}
BLYNK_WRITE(V21) // NOTAUS
{
  idlestate = param.asInt();
  if (idlestate == 1) {
    idleMode = 1;
  }
  else {
    idleMode = 0;
  }
}

//MeatDone set by Blynk
BLYNK_WRITE(V13)  // meatdone temp down
{
  meatDown = param.asInt();
  if (meatDown == 1) {
    meatDownFunc();
  }
}
BLYNK_WRITE(V14) // meatdone temp up
{
  meatUp = param.asInt();
  if (meatUp == 1) {
    meatUpFunc();
  }
}
void meatDownFunc()
{
  meatDone = meatDone - 1;
  Blynk.virtualWrite(V10, meatDone);
}
void meatUpFunc()
{
  meatDone = meatDone + 1;
  Blynk.virtualWrite(V10, meatDone);
}
// MeatDone2 set by Blynk
BLYNK_WRITE(V15)  // meatdone temp down
{
  meatDown2 = param.asInt();
  if (meatDown2 == 1) {
    meatDownFunc2();
  }
}
BLYNK_WRITE(V16) // meatdone temp up
{
  meatUp2 = param.asInt();
  if (meatUp2 == 1) {
    meatUpFunc2();
  }
}
void meatDownFunc2()
{
  meatDone2 = meatDone2 - 1;
  Blynk.virtualWrite(V11, meatDone2);
}
void meatUpFunc2()
{
  meatDone2 = meatDone2 + 1;
  Blynk.virtualWrite(V11, meatDone2);
}
//MeatDone 3 set by Blynk
BLYNK_WRITE(V17)  // meatdone temp down
{
  meatDown3 = param.asInt();
  if (meatDown3 == 1) {
    meatDownFunc3();
  }
}
BLYNK_WRITE(V18) // meatdone temp up
{
  meatUp3 = param.asInt();
  if (meatUp3 == 1) {
    meatUpFunc3();
  }
}
void meatDownFunc3()
{
  meatDone3 = meatDone3 - 1;
  Blynk.virtualWrite(V12, meatDone3);
}
void meatUpFunc3()
{
  meatDone3 = meatDone3 + 1;
  Blynk.virtualWrite(V12, meatDone3);
}
void tempDownFunc()
{
  setPoint = setPoint - 1;
  Blynk.virtualWrite(V6, setPoint);
}
void tempUpFunc()
{
  setPoint = setPoint + 1;
  Blynk.virtualWrite(V6, setPoint);
}
void sendData()
{
  if (WiFi.status() == WL_CONNECTED) {

    if (logMode != 1)
      return;
    Serial.println("try to send");
    if (client.connect(host, 80)) {
      // compose ThindSpeak update data url
      String url = "/update?key=";
      url = url + writeAPIKey;
      url = url + "&field1=";
      url = url + String(air);
      url = url + "&field2=";
      url = url + String(meat);
      url = url + "&field3=";
      url = url + String(meat2);
      url = url + "&field4=";
      url = url + String(meat3);
      url = url + "\r\n";
      // This will send the request to the ThingSpeak
      if (WiFi.status() == WL_CONNECTED) {
        client.print(String("GET ") + url + " HTTP/1.1\r\n" +
                     "Host: " + host + "\r\n" +
                     "Connection: close\r\n\r\n");
      }
    }
    client.stop();
  }
}
void sendPush()
{
  if (WiFi.status() == WL_CONNECTED) {
    if (pushMode != 1)
      return;
    Serial.println("try to push");
    if (air < lowTemp)
    {
      Blynk.notify("!!!Low Temp!!!");
    }
    if (air > highTemp)
    {
      Blynk.notify("!!!High Temp!!!");
    }
    if (meat > meatDone)
    {
      Blynk.notify("!!!Meat Done!!!");
    }
    if (meat2 > meatDone2)
    {
      Blynk.notify("!!!Meat2 Done!!!");
    }
    if (meat3 > meatDone3)
    {
      Blynk.notify("!!!Meat3 Done!!!");
    }
  }
}
void readSensors()
{
  digitalWrite(pA, LOW);
  digitalWrite(pB, LOW);
  digitalWrite(pC, LOW);
  rn = rn1;
  Acalc = A;
  Bcalc = B;
  Ccalc = C;
    Serial.println(A);
  calcTemp();
    Serial.println(f0);
  if (f0 < 0)                                             // If value is not a number, assign an arbitrary value
  {
    air = 0;
  }
  else
  {
    air = f0;                                                    // Otherwise use the calculated value
    Serial.println(air);
  }
  Blynk.virtualWrite(V0, air);
  // request Meat 1:
  digitalWrite(pA, HIGH);
  digitalWrite(pB, LOW);
  digitalWrite(pC, LOW);
  rn = rn2;
  Acalc = A2;
  Bcalc = B2;
  Ccalc = C2;
  calcTemp();
  if (f0 < 0)                                                // If value is not a number, assign an arbitrary value
  {
    meat = 0;
  }
  else
  {
    meat = f0;                                                    // Otherwise use the calculated value

  }
  Blynk.virtualWrite(V1, meat);
  // request Meat 2:
  digitalWrite(pA, LOW);
  digitalWrite(pB, HIGH);
  digitalWrite(pC, LOW);
  rn = rn3;
  Acalc = A3;
  Bcalc = B3;
  Ccalc = C3;
  calcTemp();
  if (f0 < 0)                                                // If value is not a number, assign an arbitrary value
  {
    meat2 = 0;
  }
  else
  {
    meat2 = f0;                                                    // Otherwise use the calculated value

  }
  Blynk.virtualWrite(V2, meat2);
  // request Meat 3:
  digitalWrite(pA, HIGH);
  digitalWrite(pB, HIGH);
  digitalWrite(pC, LOW);
  rn = rn4;
  Acalc = A4;
  Bcalc = B4;
  Ccalc = C4;
  calcTemp();
  if (f0 < 0)                                              // If value is not a number, assign an arbitrary value
  {
    meat3 = 0;
  }
  else
  {
    meat3 = f0;                                                    // Otherwise use the calculated value

  }
  Blynk.virtualWrite(V3, meat3);


}
void calcTemp() {
  a0 = analogRead(0);   // This reads the "voltage" value on A0. Value is actually divided into 1024 steps from 0-1023.
  v0 = a0 * .00322;                                       // Converts A0 value to an actual voltage (3.3V / 1024 steps = .00322V/step.
  r0 = (((r2 * vin) / v0) - r2);                         // Calculates resistance value of thermistor based on fixed resistor value and measured voltage
  rref = r0 / (rn * 1000);
  logr0 = log(rref);
  k0 = 1.0 / (Acalc + (Bcalc * logr0) + (Ccalc * logr0 * logr0));        // Steinhart-Hart Equation to calculate temperature in Kelvin
  f0 = k0 - 273;                                        // Convert temperature to celsius
}
void updateDisplay()
{
  Blynk.virtualWrite(V6, setPoint);
  Blynk.virtualWrite(V7, logMode);
  Blynk.virtualWrite(V8, pushMode);
  Blynk.virtualWrite(V19, httpMode);
  Blynk.virtualWrite(V10, meatDone);
  Blynk.virtualWrite(V11, meatDone2);
  Blynk.virtualWrite(V12, meatDone3);
  switch (displaymode) {
    case 1:
      updateDisplaytemp();
      displaymode = 2;
      break;
    case 2:
      updateDisplayEvent();
      displaymode = 1;
      break;
  }
}
void pushHeat()
{
  Input = air;
  Input2 = air;
  myPID.Compute();
  myPID2.Compute();
  val2 = map(Output, 0, 255, 0, 300);
  val = map(Output2, 0, 255, 0, 300);     // scale it to use it with the servo (value between 0 and 180)
  if (val2 > 1) {
    val2 = val2 + 50;
  }
  if (val > 0) {
    //    val2 = val2 + 30;
  }
  if (air > highTemp)
  {
    val2 = 0;
    val = 0;
  }
  if (idleMode == 1)
  {
    val2 = 0;
    val = 0;
  }
  analogWrite(pushPin, val2);
  //  myservo.write(val);                  // sets the servo position according to the scaled value

  //going slow to save power litle lm7805
  if (val > valservo) {
    for (int i = valservo; i <= val; i++) {
      myservo.write(i);
      delay(10);
      valservo = i;
    }
  }
  else {
    for (int i = valservo; i >= val; i--) {
      myservo.write(i);
      valservo = i;
      delay(10);
    }
  }

  if (val2 > 0) {
    FAN.on();
  }
  else {
    FAN.off();
  }
  if (val > 0) {

    KLAPPE.on();
  }
  else {
    KLAPPE.off();
  }
}
void updateDisplaytemp()
{
  if (probecount <= 2)
  {
    lcd.clear();
    lcd.setCursor(0, 0);
    lcd.print("Smoker:");
    if (air < lowlim)
    {
      lcd.print(" N/A");
    }
    else if (air > lowlim & air < 100)
    {
      lcd.print(" "); //pad with a space
      lcd.print(air);
      lcd.print(" C");
    }
    else
    {
      lcd.print(air);
      lcd.print(" C");
    }
    lcd.setCursor(0, 1);
    lcd.print("Meat:");
    if (meat < lowlim)
    {
      lcd.print(" N/A");
    }
    else if (meat > lowlim & meat < 100)
    {
      lcd.print(" "); //pad with a space
      lcd.print(meat);
      lcd.print(" C");
    }
    else
    {
      lcd.print(meat);
      lcd.print(" C");
    }
  }
  else {
    lcd.clear();
    lcd.setCursor(0, 0);
    lcd.print("S:");
    if (air < lowlim)
    {
      lcd.print(" N/A");
    }
    else
    {
      lcd.print(air);
    }
    lcd.setCursor(9, 0);
    lcd.print("1:");
    if (meat < lowlim)
    {
      lcd.print(" N/A");
    }

    else
    {
      lcd.print(meat);
    }
    lcd.setCursor(0, 1);
    lcd.print("2:");
    if (meat2 < lowlim)
    {
      lcd.print(" N/A");
    }
    else
    {
      lcd.print(meat2);
    }
    lcd.setCursor(9, 1);
    lcd.print("3:");
    if (meat3 < lowlim)
    {
      lcd.print(" N/A");
    }

    else
    {
      lcd.print(meat3);
    }
  }
}
void updateDisplayEvent()
{
  if (air < lowTemp)
  {
    lcd.clear();
    lcd.home();
    lcd.setCursor(2, 0);
    lcd.print("!!Low Temp!!");
  }
  else  if (air > lowTemp & air < highTemp)
  {
    updateDisplaytemp();
  }
  else if (air > highTemp)
  {
    lcd.clear();
    lcd.home();
    lcd.setCursor(1, 0);
    lcd.print("!!High Temp!!");
  }
  if (meat > meatDone)
  {
    lcd.clear();
    lcd.home();
    lcd.setCursor(2, 0);
    lcd.print("!Meat Finish!");
  }
  if (meat2 > meatDone2)
  {
    lcd.clear();
    lcd.home();
    lcd.setCursor(2, 0);
    lcd.print("!Meat2 Finish!");
  }
  if (meat3 > meatDone3)
  {
    lcd.clear();
    lcd.home();
    lcd.setCursor(2, 0);
    lcd.print("!Meat3 Finish!");
  }
}
void click1() {
  Serial.println("Button 1 click.");
  switch (menue) {
    case 1:
      setPoint --;
      updateDisplaymenue();
      break;
    case 2:
      meatDone --;
      updateDisplaymenue();
      break;
    case 3:
      meatDone2 --;
      updateDisplaymenue();
      break;
    case 4:
      meatDone3 --;
      updateDisplaymenue();
      break;
    case 5:
      probecount --;
      if (probecount < 1) probecount = 4;
      updateDisplaymenue();
      break;
  }
} // click1
void doubleclick1() {
  Serial.println("Button 1 doubleclick.");
  menue ++;
  if (menue > 8) menue = 0;
  updateDisplaymenue();
  // Serial.println(menue);
}
void doubleclick2() {
  Serial.println("Button 1 doubleclick.");
  menue --;
  if (menue < 1) menue = 8;
  updateDisplaymenue();
  // Serial.println(menue);
}
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

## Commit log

2018-09-07 Teileliste erstellt
    [Teileliste.xlsx]
2018-09-07 option Display
    [Teileliste.xlsx]
2018-09-14 update push and servo speed
    removed Pushingbox.
    Push is done with blynk
    changed servo speed to save power and cool down the litle lm7805
2018-09-18 probe.h included
2018-09-23 Big Update V3.1
    [Teileliste.xlsx, button.skp, button.stl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]
2018-09-24 New NodeMCU AZDelivery is crap!!
    [Teileliste.xlsx]
2018-09-25 Diode added
    [Teileliste.xlsx]
2018-09-25 3d-Print update
    [Teileliste.xlsx, button.skp, button.stl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]
2018-09-29 update Gerber V3.2
    DC-Plug Positiv Polarity
2018-09-29 3-D Druck klappe
    [box.stl, servodamper-rotor.stl]
2019-05-06 fixed wrong value for Servo
    [V3_Code.ino]
